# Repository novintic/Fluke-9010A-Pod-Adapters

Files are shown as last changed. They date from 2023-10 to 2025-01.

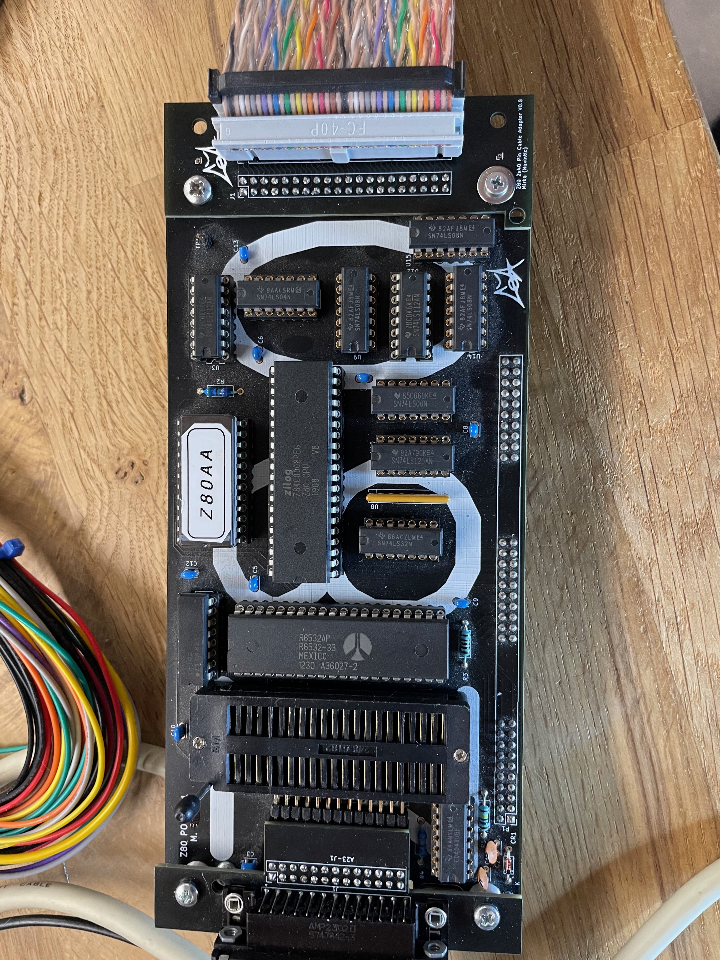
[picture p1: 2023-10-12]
Fluke Adapter Pics/IMG_5715.jpeg

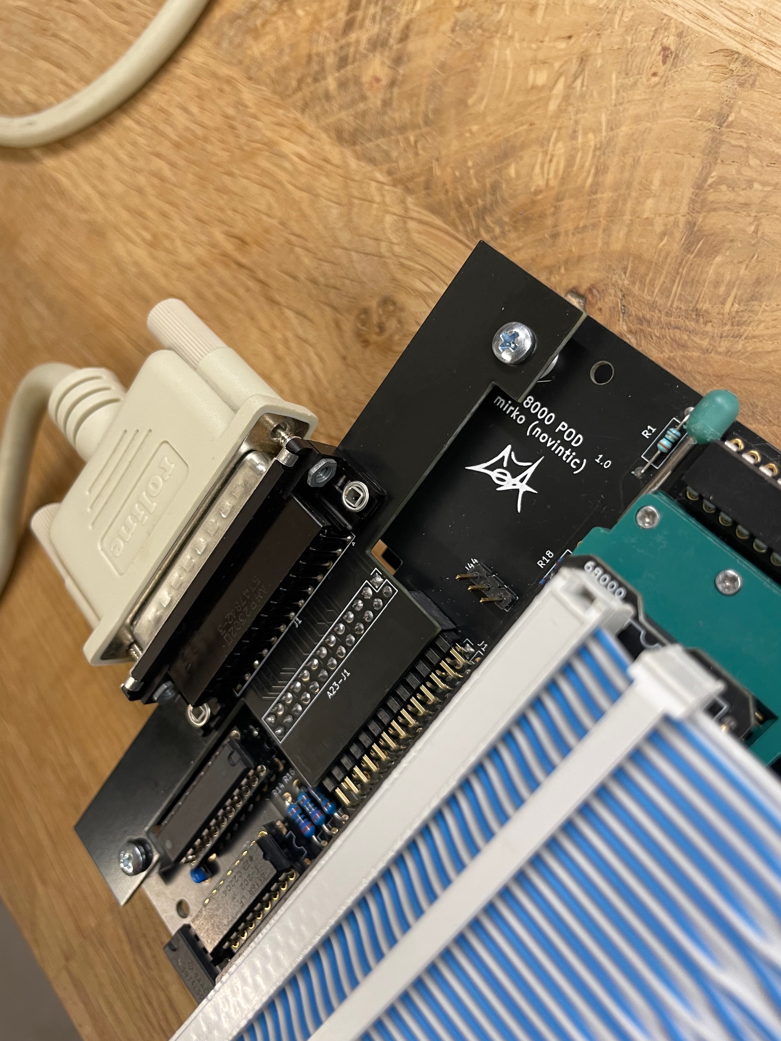
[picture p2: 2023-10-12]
Fluke Adapter Pics/IMG_5681.jpeg

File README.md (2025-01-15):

# Fluke-9010A-Pod-Adapters

Some quality of life improvements for Fluke 9010A Reproduction Pod users:

Fluke Pod adapter: use a standard DB 25 cable with your repro pod. Should work with the 'small' pods like Z80 and 6502. For Z80 you will need to use a low footprint crystal for the adapter to fit.

Fluke Pod adapter large: use a standard DB 25 cable with your repro pod. Should work with the 'large' pods like 6809 and 68000.

Z80 and 6502 Pod 2x40 Pin Cable: Use a double 40pin ribbon cable to get better signal quality / more stable interfacing even with longer cables.

If you don't know what all this means, you probably won't need any of it..;)

Have fun

01/2025
Added 6502 2x40 pin cable

07/2024
Uploaded files for 6809 and 68K pod-to-UUT cable headers too.

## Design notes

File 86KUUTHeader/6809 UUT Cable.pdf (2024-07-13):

## Fluke 9010a 6809 Pod UUT- Cable

### 1) Background

The POD-to-UUT- cables come in basically 2 variants:
- 1x40 PIN ribbon- cable which is easy to make using ‚standard‘ crimping parts. This kind of cable is used in the original Z80 and 6502 Pods for example.
- A 2x40 pin variant is used in later pods (like the 6809). This type of cable uses obviously double the amount of wires in a ‚twisted pair‘ pattern; signal wires alternating with ground ones. This kind of configuration provides some shielding and essentially balanced connections.
- The latter type of UUT cables seems to be essential for the 6809 pod to run reliably. While for some UUTs / some basic testing a single 40 pin cable may be sufficient, most others won’t run at all or behave extremely flaky.
- Since the position of the ground PIN changes from CPU to CPU, these cables are not interchangeable between different pods.
- Also, these cables are not easy to reproduce. This means that if you own an original pod and brake its UUT connector this will present a problem.

### 2) Reproducing a POD-to-UUT Cable

- One way to reproduce such a cable is to manually solder every second wire to a 40 pin socket and then connecting every other wire together and to the ground pin. This is a very tedious process and not fun at all.
- This little PCB allows the use of simple ‚straight 40 PIN IDC connectors. It seems to work reliably even if the cables used are longer than the original ones. The cables are very easy to make.

The ‚6809’- label marks the position of pin 1 if viewed from the top

6809 UUT cable V1.1 | page 1 of 3
1 | 20
40 | 21

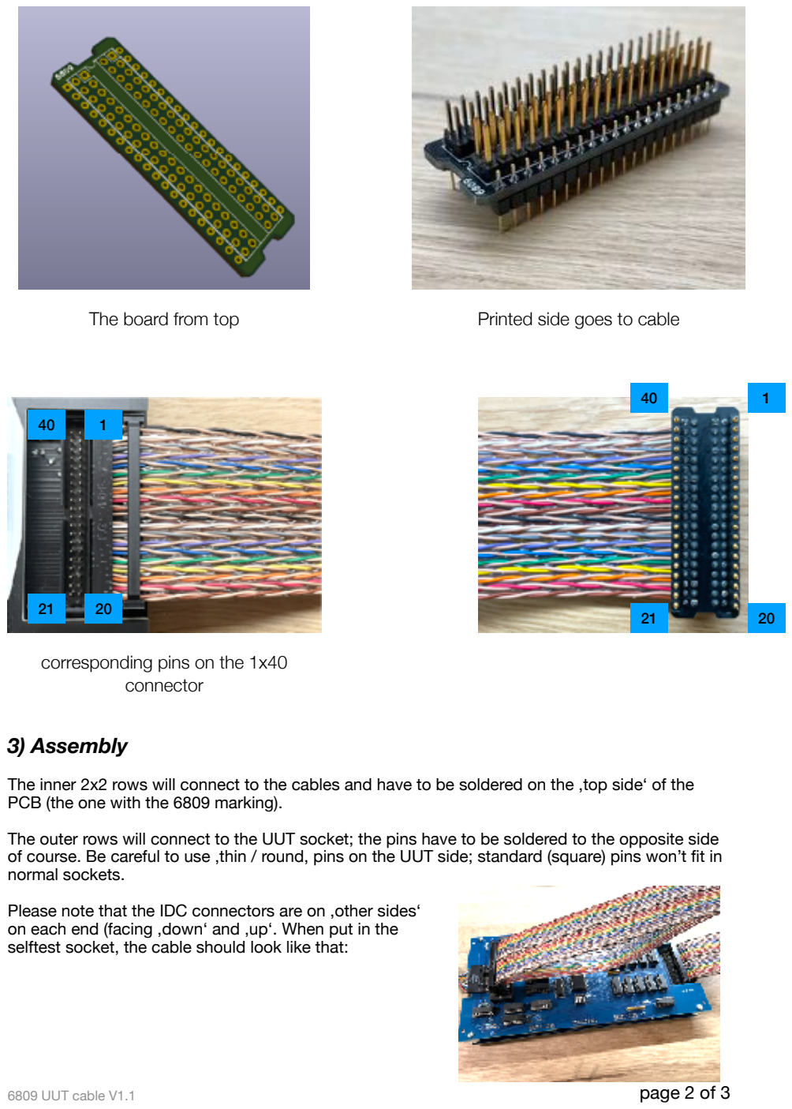
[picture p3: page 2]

### 3) Assembly

The inner 2x2 rows will connect to the cables and have to be soldered on the ‚top side‘ of the PCB (the one with the 6809 marking).

The outer rows will connect to the UUT socket; the pins have to be soldered to the opposite side of course. Be careful to use ‚thin / round‚ pins on the UUT side; standard (square) pins won’t fit in normal sockets.

Please note that the IDC connectors are on ‚other sides‘
on each end (facing ‚down‘ and ‚up‘. When put in the
selftest socket, the cable should look like that:
The board from top | Printed side goes to cable

corresponding pins on the 1x40 connector

21 20

40 1

21 20

40 1

Before powering on please check continuity / position between the 1x 40 PIN connector on the pod (see pin numbering above) and the UUT connector and make sure there are no shorts between pins (if the board was populated on the wrong sides, all UUT PINS could be shorted!).

### 4) Part list (examples from digikey)

- 1x adapter PCB
- 2x 40 PIN ribbon Cable. Used above were twisted pair ones. https://www.digikey.ch/product-detail/de/3m/1700-40-100/3M157910-5-ND/9478781
- 4x straight IDC connectors: https://www.digikey.ch/product-detail/de/assmann-wsw-components/AWP-40-7240-T/HHKC40H-ND/5040123 (https://www.digikey.ch/product-detail/de/assmann-wsw-components/AWP-40-7240-T/HHKC40H-ND/5040123)
- 2x 40 PIN straight headers: https://www.digikey.ch/product-detail/de/molex/0901310780/WM8152-ND/760866
- 2x 20 PIN single row pins/headers: https://www.digikey.ch/product-detail/de/precidip/350-10-132-00-001101/1212-1139-ND/
3757389 (https://www.digikey.ch/product-detail/de/preci-dip/350-10-132-00-001101/1212-1139-ND/3757389)
Note: thinner pins on UUT side

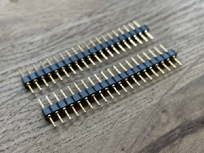
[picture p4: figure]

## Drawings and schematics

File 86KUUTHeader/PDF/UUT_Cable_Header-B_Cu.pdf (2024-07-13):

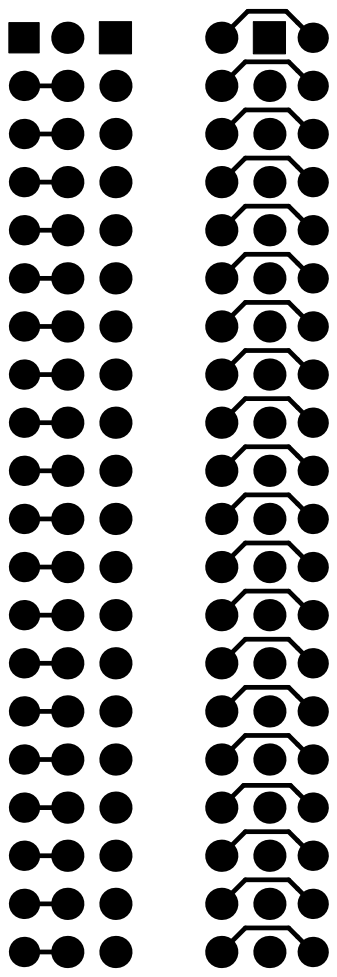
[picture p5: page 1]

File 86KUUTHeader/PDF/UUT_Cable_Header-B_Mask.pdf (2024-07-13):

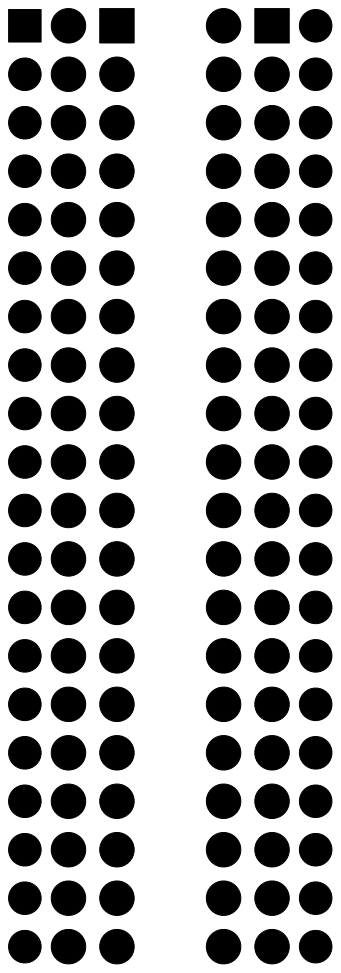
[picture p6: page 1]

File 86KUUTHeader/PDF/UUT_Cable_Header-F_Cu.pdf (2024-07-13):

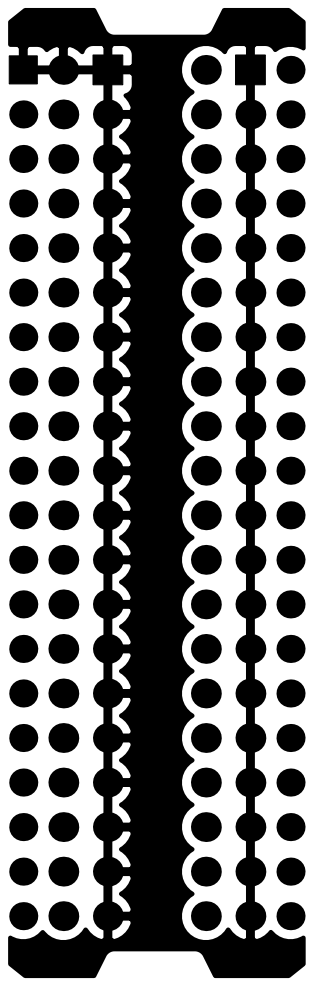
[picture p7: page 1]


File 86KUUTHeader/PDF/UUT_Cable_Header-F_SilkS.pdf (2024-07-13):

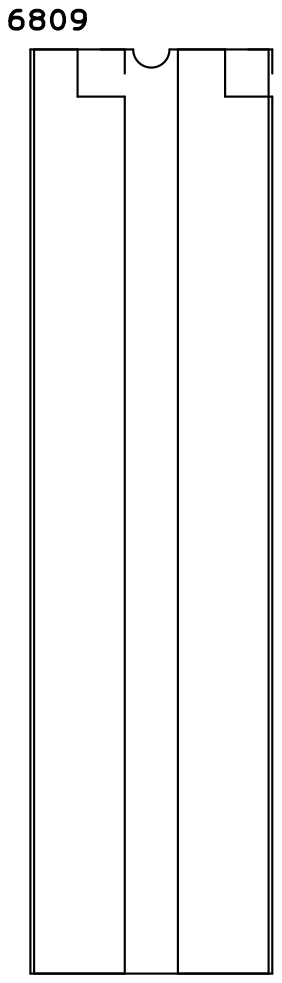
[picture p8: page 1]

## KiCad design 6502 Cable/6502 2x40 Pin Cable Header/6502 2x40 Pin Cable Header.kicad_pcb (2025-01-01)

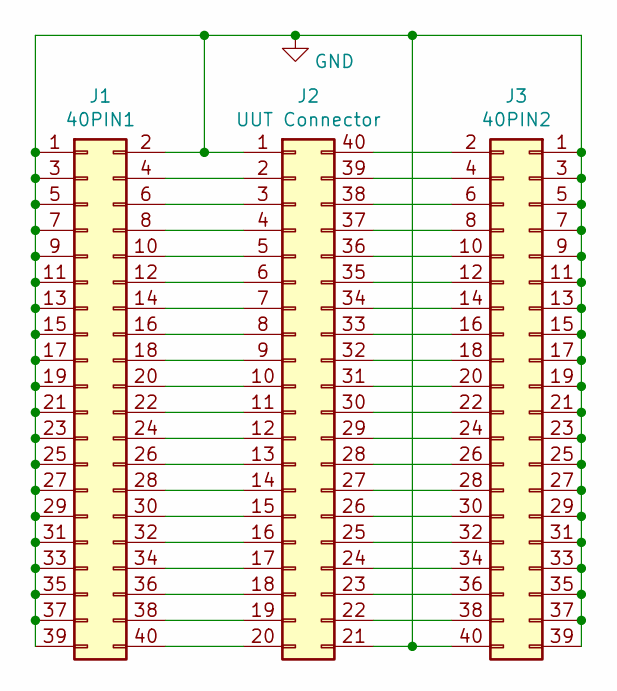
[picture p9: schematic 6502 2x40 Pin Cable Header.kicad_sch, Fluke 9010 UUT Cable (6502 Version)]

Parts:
J1: 40PIN1; PinSocket_2x20_P2.54mm_Vertical
J2: UUT Connector; DIP-40_W15.24mm
J3: 40PIN2; PinSocket_2x20_P2.54mm_Vertical

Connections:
GND: J1.1, J1.2, J1.3, J1.5, J1.7, J1.9, J1.11, J1.13, J1.15, J1.17, J1.19, J1.21, J1.23, J1.25, J1.27, J1.29, J1.31, J1.33, J1.35, J1.37, J1.39, J2.1, J2.21, J3.1, J3.3, J3.5, J3.7, J3.9, J3.11, J3.13, J3.15, J3.17, J3.19, J3.21, J3.23, J3.25, J3.27, J3.29, J3.31, J3.33, J3.35, J3.37, J3.39, J3.40
unnamed: J1.4, J2.2
unnamed: J1.6, J2.3
unnamed: J1.8, J2.4
unnamed: J1.10, J2.5
unnamed: J1.12, J2.6
unnamed: J1.14, J2.7
unnamed: J1.16, J2.8
unnamed: J1.18, J2.9
unnamed: J1.20, J2.10
unnamed: J1.22, J2.11
unnamed: J1.24, J2.12
unnamed: J1.26, J2.13
unnamed: J1.28, J2.14
unnamed: J1.30, J2.15
unnamed: J1.32, J2.16
unnamed: J1.34, J2.17
unnamed: J1.36, J2.18
unnamed: J1.38, J2.19
unnamed: J1.40, J2.20
unnamed: J2.22, J3.38
unnamed: J2.23, J3.36
unnamed: J2.24, J3.34
unnamed: J2.25, J3.32
unnamed: J2.26, J3.30
unnamed: J2.27, J3.28
unnamed: J2.28, J3.26
unnamed: J2.29, J3.24
unnamed: J2.30, J3.22
unnamed: J2.31, J3.20
unnamed: J2.32, J3.18
unnamed: J2.33, J3.16
unnamed: J2.34, J3.14
unnamed: J2.35, J3.12
unnamed: J2.36, J3.10
unnamed: J2.37, J3.8
unnamed: J2.38, J3.6
unnamed: J2.39, J3.4
unnamed: J2.40, J3.2

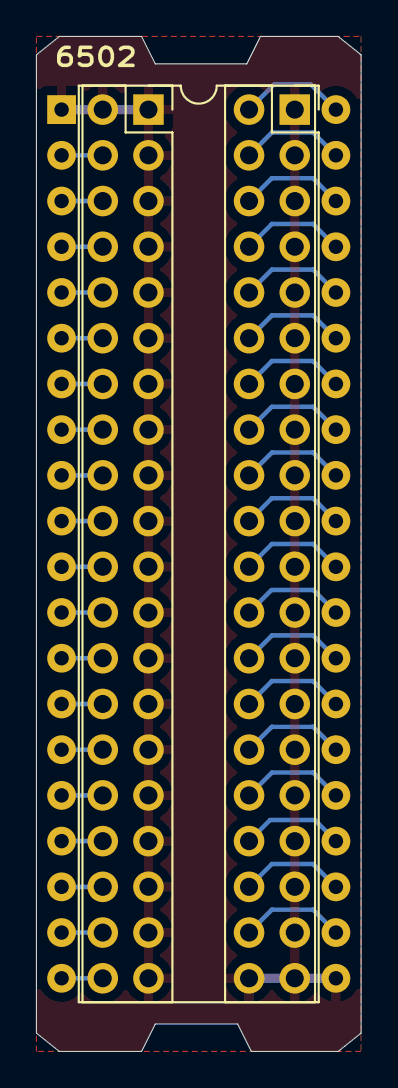
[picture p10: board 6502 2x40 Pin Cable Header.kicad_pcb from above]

Board: 2 copper layers, 18.0 x 56.4 mm, 3 parts (0 on the bottom side), 39 nets.

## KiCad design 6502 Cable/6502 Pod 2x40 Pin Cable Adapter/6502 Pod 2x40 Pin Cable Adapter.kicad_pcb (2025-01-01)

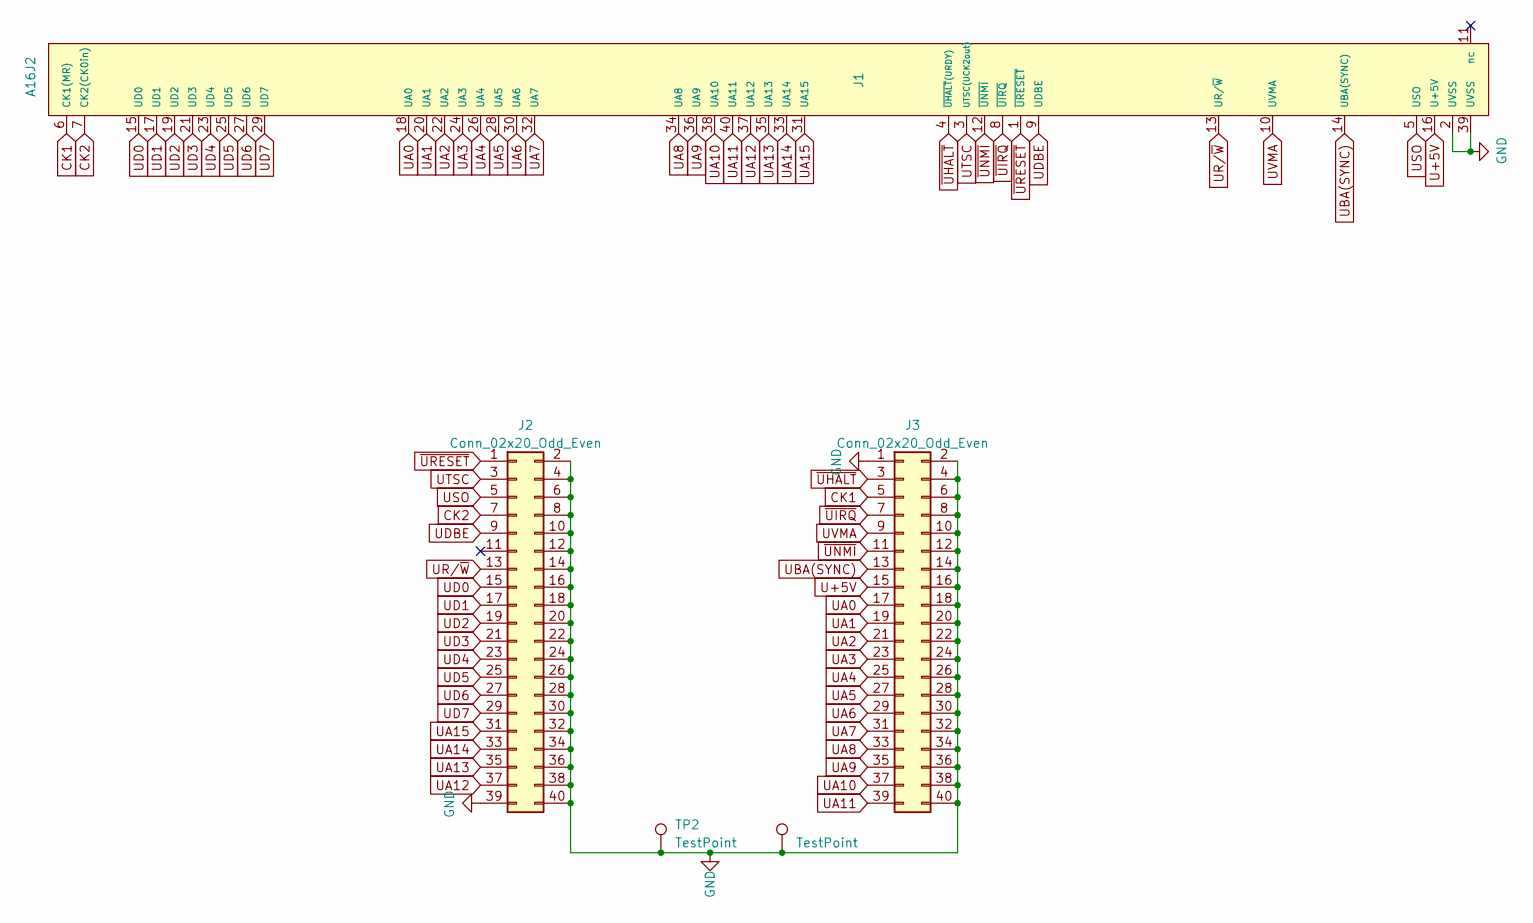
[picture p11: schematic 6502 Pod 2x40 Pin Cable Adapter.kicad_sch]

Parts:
J1: A16J2; PinHeader_2x20_P2.54mm_Vertical
J2, J3: Conn_02x20_Odd_Even; PinHeader_2x20_P2.54mm_Vertical
TP1, TP2: TestPoint; PinHeader_1x01_P1.00mm_Vertical

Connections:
CK1: J1.6 (CK1(MR)), J3.5
CK2: J1.7 (CK2(CK0in)), J2.7
GND: J1.2 (UVSS), J1.39 (UVSS), J2.2, J2.4, J2.6, J2.8, J2.10, J2.12, J2.14, J2.16, J2.18, J2.20, J2.22, J2.24, J2.26, J2.28, J2.30, J2.32, J2.34, J2.36, J2.38, J2.39, J2.40, J3.1, J3.2, J3.4, J3.6, J3.8, J3.10, J3.12, J3.14, J3.16, J3.18, J3.20, J3.22, J3.24, J3.26, J3.28, J3.30, J3.32, J3.34, J3.36, J3.38, J3.40, TP1.1, TP2.1
U+5V: J1.16 (U+5V), J3.15
UA0: J1.18 (UA0), J3.17
UA1: J1.20 (UA1), J3.19
UA2: J1.22 (UA2), J3.21
UA3: J1.24 (UA3), J3.23
UA4: J1.26 (UA4), J3.25
UA5: J1.28 (UA5), J3.27
UA6: J1.30 (UA6), J3.29
UA7: J1.32 (UA7), J3.31
UA8: J1.34 (UA8), J3.33
UA9: J1.36 (UA9), J3.35
UA10: J1.38 (UA10), J3.37
UA11: J1.40 (UA11), J3.39
UA12: J1.37 (UA12), J2.37
UA13: J1.35 (UA13), J2.35
UA14: J1.33 (UA14), J2.33
UA15: J1.31 (UA15), J2.31
UBA(SYNC): J1.14 (UBA(SYNC)), J3.13
UD0: J1.15 (UD0), J2.15
UD1: J1.17 (UD1), J2.17
UD2: J1.19 (UD2), J2.19
UD3: J1.21 (UD3), J2.21
UD4: J1.23 (UD4), J2.23
UD5: J1.25 (UD5), J2.25
UD6: J1.27 (UD6), J2.27
UD7: J1.29 (UD7), J2.29
UDBE: J1.9 (UDBE), J2.9
UR/~W: J1.13 (UR/~W), J2.13
USO: J1.5 (USO), J2.5
UTSC: J1.3 (UTSC(UCK2out)), J2.3
UVMA: J1.10 (UVMA), J3.9
~UHALT: J1.4 (~UHALT(URDY)), J3.3
~UIRQ: J1.8 (~UIRQ), J3.7
~UNMI: J1.12 (~UNMI), J3.11
~URESET: J1.1 (~URESET), J2.1

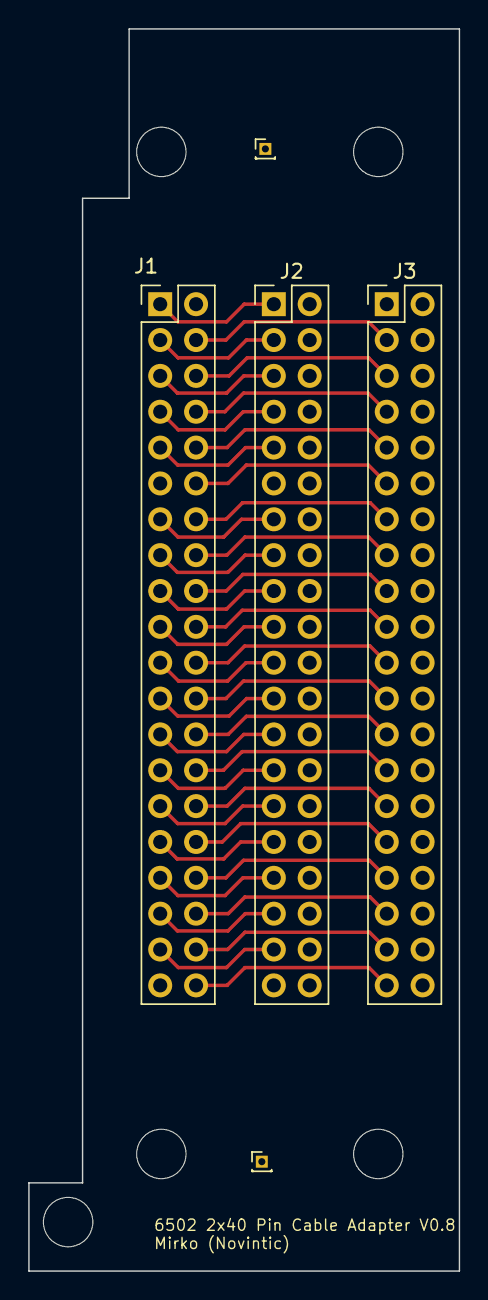
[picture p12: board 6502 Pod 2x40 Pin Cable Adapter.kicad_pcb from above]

Board: 2 copper layers, 30.5 x 88.0 mm, 5 parts (0 on the bottom side), 38 nets.

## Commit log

2024-07-13 Add files via upload
    Header PCB for 6809(E) Pod-to-UUT cable
    [UUT_Cable_Header-B_Cu.gbr, UUT_Cable_Header-B_Mask.gbr, UUT_Cable_Header-B_Paste.gbr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]
2024-07-13 Add files via upload
    Header PCB for 68K pod-to-UUT cable
    [86KUUTHeader-B_Cu.gbr, 86KUUTHeader-B_Mask.gbr, 86KUUTHeader-B_Paste.gbr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]
